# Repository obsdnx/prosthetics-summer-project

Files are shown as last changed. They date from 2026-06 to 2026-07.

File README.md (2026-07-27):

# Partial-Hand Prosthesis — Summer 2026

A co-design project to build a custom, body-powered prosthetic hand attachment for a specific client (Bassie), who has a limb difference affecting both hands. The device restores a functional grasp using 3D-printed parts and a cable-driven mechanism — no motors, no batteries.

---

## Goal

Design, prototype, and iterate on a body-powered prosthetic hand that:
- Restores functional grasp (closing fingers around an object and holding it) for a client with a partial-hand limb difference
- Is driven entirely by the user's own residual motion — thumb movement tensions a cable that closes the fingers; elastic bands return them
- Is 3D-printed so the team can go from a CAD change to a physical part in a few hours
- Is custom-fitted to the client's anatomy via a moulded thermoplastic baseplate
- Can be iterated rapidly in a university workshop setting

Two hands are being developed in parallel but with separate design tracks. The **right hand** (more tractable) is developed first; solutions are then adapted to the **left hand**, which has less residual motion and different anatomy.

---

## Mechanism

The adopted design combines two approaches:

| Approach | Source | Role |
|---|---|---|
| Cable + thumb-driven closing | Harshad | Active closing: thumb motion pulls a 0.55 mm cable routed through two capstans on the back of the hand, flexing all fingers simultaneously |
| Elastic band passive return | Fern (adapted from WILMER) | Passive opening: rubber bands return the fingers to their resting position when cable tension releases |

This gives a stronger and more controllable grasp than either approach alone. The mechanism is **underactuated** — one thumb input closes multiple joints across multiple fingers, and fingers naturally conform to the shape of whatever they grip.

---

## Components

| Component | Description |
|---|---|
| Thermoplastic baseplate | Rhinoplasty strips moulded directly to the back of the client's hand, then hardened — everything rivets or bonds to this |
| Capstans (×2) | Cable routing drums riveted to the baseplate; one thumb pull couples flexion across multiple fingers |
| Össur-style linkage digits | 5-part rigid linkage finger (Fern's design); 5 mm holes for metal dowel pin joints |
| Rolling contact joints (RCJ) | Alternative joint type — curved surfaces roll rather than pivot, no hardware needed; scaled to 50%, mirrored, with flanges |
| Knuckle hinge joints | 5 per hand × 2 hands; anchor the finger mechanisms to the baseplate at each knuckle |
| 0.55 mm cable | Runs from thumb through capstans to fingers |
| Elastic bands | Passive extension return |
| Magnetic wrist strap | Attachment to the hand — magnetic ends allow one-handed fastening |

**Left hand** uses a different strategy: one larger two-joint finger mechanism sized to the client's middle appendage, driven from the **wrist** rather than the thumb (wrist extension flexes the PIP joints; elastic band returns the distal joints).

---

## Project Summary

| Phase | Status |
|---|---|
| Research & concept selection | ✅ Complete (15 Jun) |
| Combined mechanism agreed | ✅ Complete (15 Jun) |
| Digit CAD (Össur-style linkage, right hand) | ✅ Complete (18 Jun) |
| Drive CAD (capstans, cable system) | ✅ Complete (18 Jun) |
| Rolling contact joint variants | ✅ Complete (18–19 Jun) |
| Attachment design (hinges, Velcro tabs, strap) | ✅ Complete (19 Jun) |
| Left-hand concept (wrist-driven) | ✅ Defined (19 Jun) |
| 3D printing & assembly | ✅ Began 22 Jun |
| First demo to Bassie | Target: 24 Jun |
| Iterative design cycle | Ongoing |

---

## Tech Stack

| Tool | Purpose |
|---|---|
| SolidWorks | Primary CAD tool for finger mechanism and wrist plate design (Varun) |
| CAD software (STEP output) | Parametric design — digits, hinges, capstans, chassis |
| Bambu Studio | Slicing STL files for the Bambu Lab X1 printer |
| Bambu Lab X1 | Primary FDM printer (PLA structural parts) |
| Ultimaker / Biolab printers | Secondary print facilities |
| Harshad's personal printer | Overnight backup printing |
| 3D scanner | Capturing client's hand geometry for custom fit |
| Thermoplastic moulding | Rhinoplasty strips shaped to the back of the hand for the baseplate |
| GitHub | Version control for CAD files, documentation, and research notes |

**Print settings:** 0.08 mm layer height, 15% infill, PLA. TPU considered for grip caps (deferred — conflicts with capacitive touch screen use).

---

## The Team

| Person | Area |
|---|---|
| Harshad | Cable-driven mechanism; owns 3D printing (personal printer backup); capstan and RCJ CAD models |
| Fern | Lead CAD for Össur-style linkage digit; WILMER elastic approach; left-hand wrist mechanism concept |
| Etienne | Rolling contact joint CAD adaptation |
| Eito | RCJ sizing for client's thumb; hollowed-out finger variant |
| Weasley | 3D modelling; design-for-manufacture; Hackspace liaison |
| Alex | Plan of Work and Hackspace access; safety/induction; fitted RCJ cap modelling |
| Anya | CAD support; 3D print/scan of left hand anatomy |
| Mervyn | Left-hand string-pulley concept; attachment methods; materials and biocompatibility research |
| Varun | Claw mechanism CAD (SolidWorks) — finger segments, wrist plate, spring hinges |
| Nikhil, Anais | Attended planning meeting (15 Jun) |

---

## Repository Structure

```
.
├── cad/
│   ├── step-files/            # STEP files for all designed components
│   ├── 3d-models/             # STL / print-ready files
│   └── varun-claw-mechanism/  # SolidWorks claw mechanism (see CAD Files below)
├── scans/                 # 3D scan data of client's hand
├── photos/
│   ├── arm/               # Fit photos on client's arm
│   └── misc/              # Build progress, prints, assembly
├── docs/                  # Meeting notes, design decisions, handover docs
└── research/              # Papers, competitor analysis, reference models
```

---

## CAD Files

### Varun — Claw Mechanism (SolidWorks)

The main finger mechanism, designed in SolidWorks. Two plate widths (original and narrow), three finger configurations, and two spring hinge variants. All files are `.SLDPRT` (parts) and `.SLDASM` (assemblies).

```
cad/varun-claw-mechanism/
├── V1-Equal-3-Segment-Hand/     # 3 equal-length segments, original plate width
├── V1-Wrist-Plate/              # Upper + lower wrist plate
├── V1-Brackets/                 # Path bracket + hook mount
├── V2-Equal-3-Segment-Hand/     # Narrow plate, equal segments
├── V2-Non-Equal-3-Segment-Hand/ # Narrow plate, varying segment lengths
├── V2-2-Segment-Hand/           # Narrow plate, 2-segment variant
├── V2-Wrist-Plate/              # Narrow wrist plate
├── V2-Brackets/                 # Path bracket + hook mount
├── V2-Spring-Hinge/             # Spring hinge assembly (th-61-1)
└── V2-Spring-Hinge-2/           # Spring hinge variant (th-61sus-1)
```

### Legacy STEP files

| Component | Version | File |
|---|---|---|
| Outer phalange | V3 | `cad/step-files/V3 Outer phalange.STEP` |
| Hinge | V2 | `cad/step-files/V2 Hinge.STEP` |

---

## Progress Photos

### Claw mechanism — July 2026

**All CAD parts laid out (V2 narrow plate)**
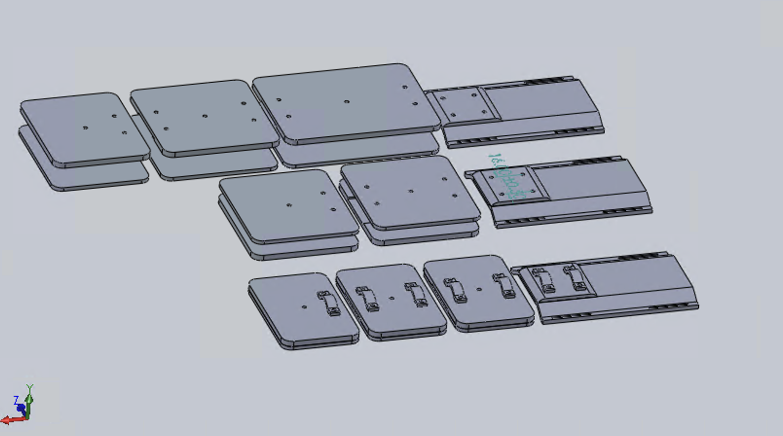
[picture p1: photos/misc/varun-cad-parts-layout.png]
Varun CAD parts layout


**Wrist plate fitted on arm with Velcro straps and spring hinge**
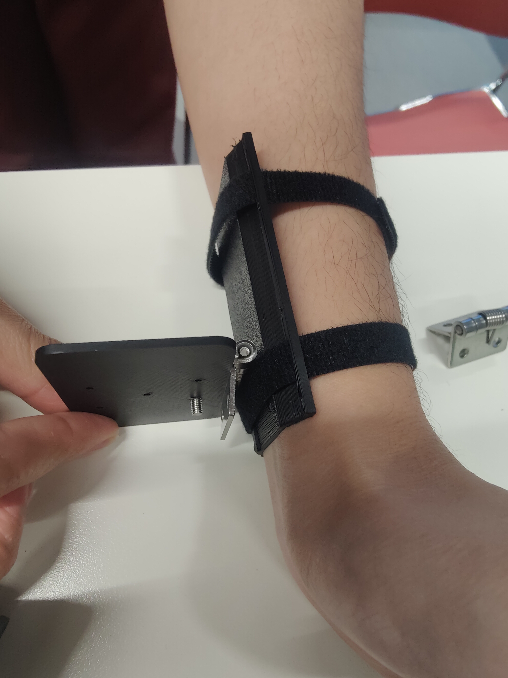
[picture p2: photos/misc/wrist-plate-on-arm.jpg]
Wrist plate on arm


**Wrist plate hinge flexing — showing range of motion**
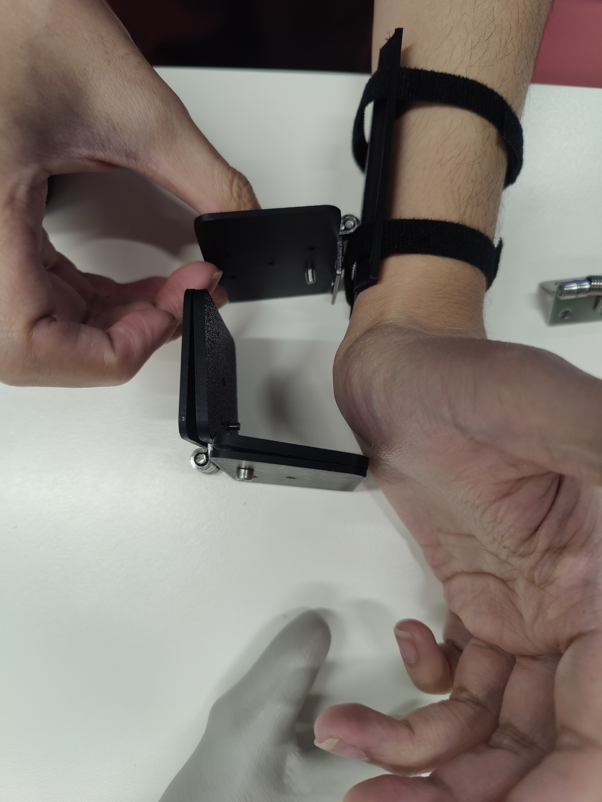
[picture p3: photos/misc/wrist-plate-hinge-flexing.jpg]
Wrist plate hinge flexing


**Full assembly — left hand (black) and right hand (yellow) with cable routing**
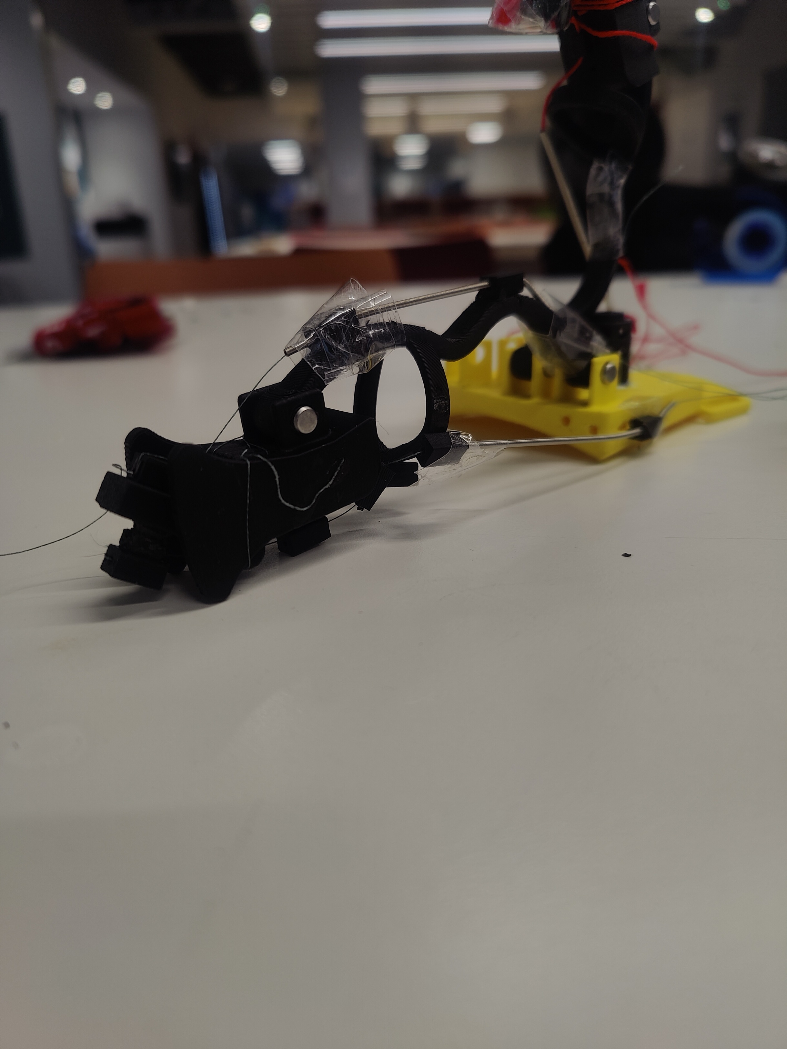
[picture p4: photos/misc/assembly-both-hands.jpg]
Both hands assembled


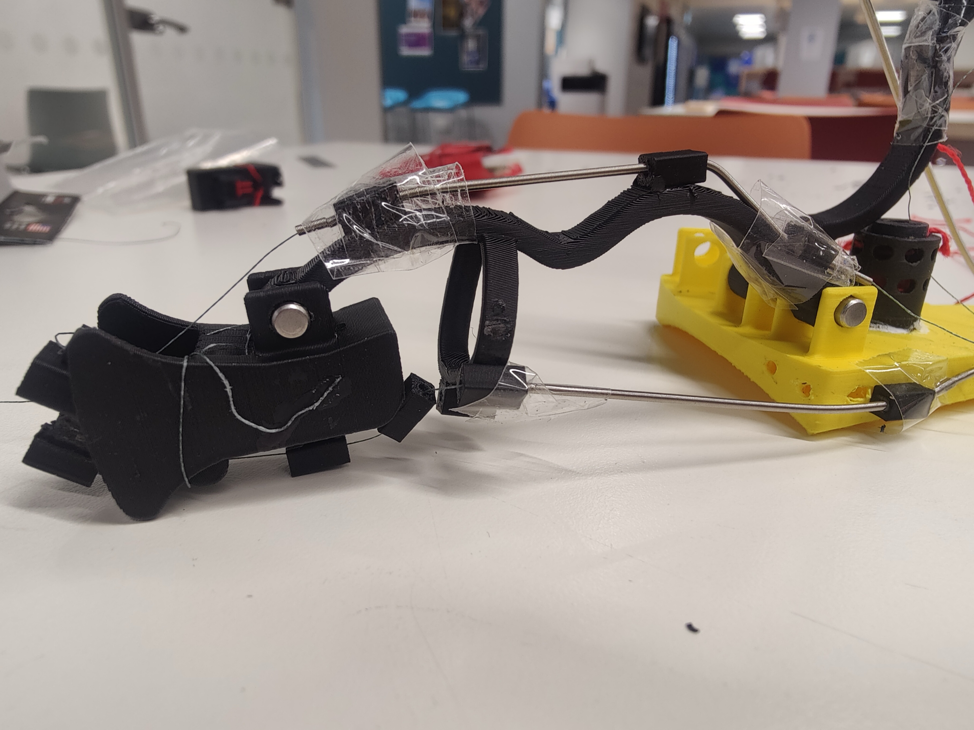
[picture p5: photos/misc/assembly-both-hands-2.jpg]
Both hands assembled, second angle


**Left hand mechanism — close-up of cable and finger segments**
Left hand cable detail

### Early chassis work

**Chassis CAD model**
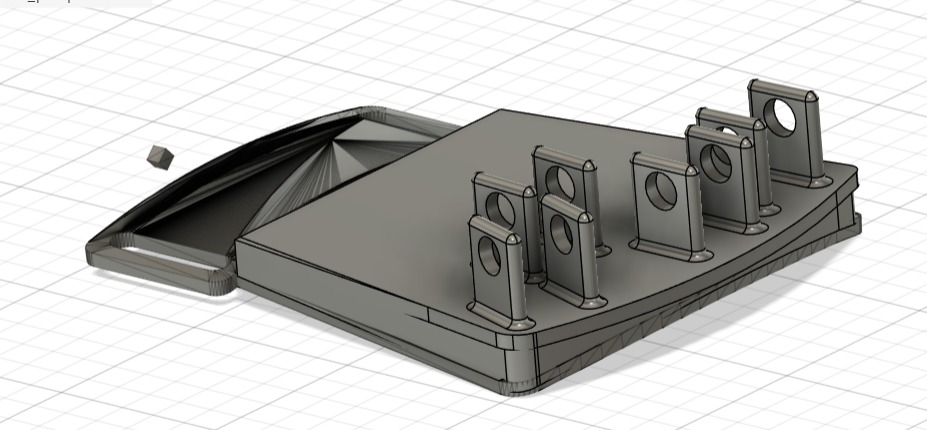
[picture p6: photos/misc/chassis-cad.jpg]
Chassis CAD model


**Chassis design fitted on hand model**
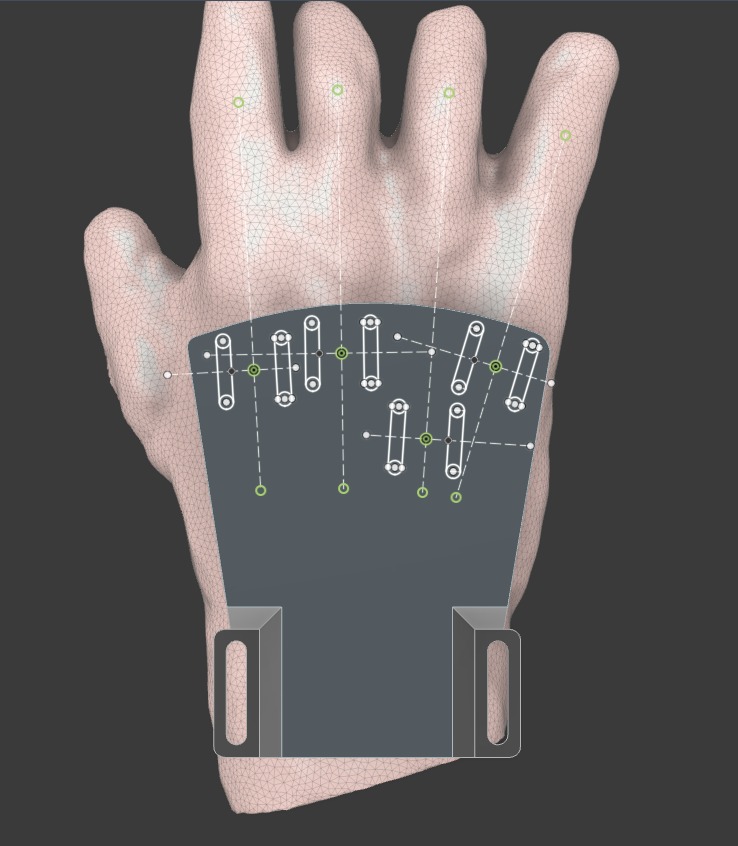
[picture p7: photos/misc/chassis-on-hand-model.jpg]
Chassis on hand model


**Physical 3D print — blue chassis**
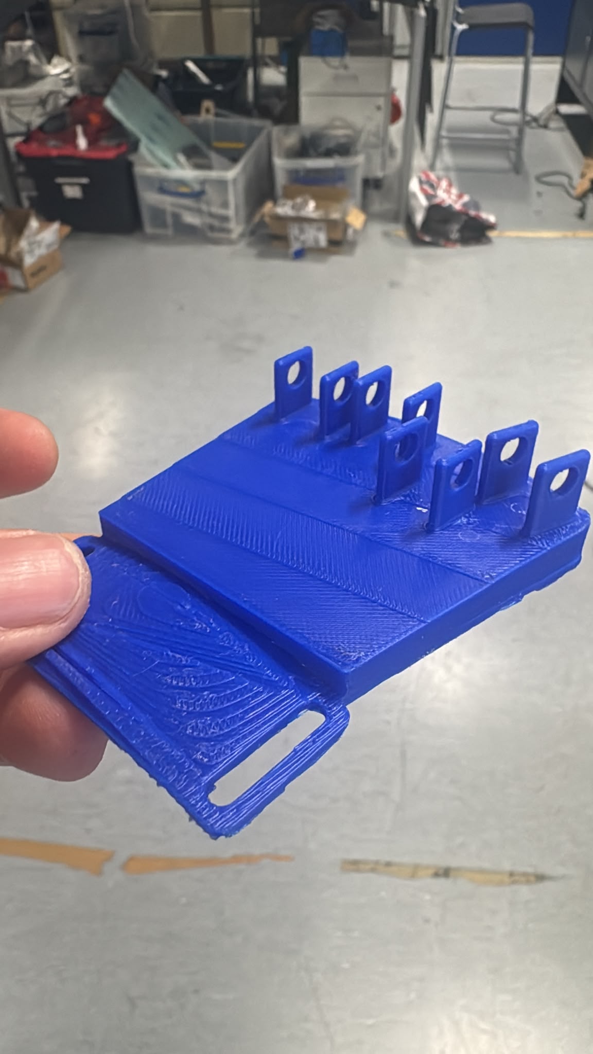
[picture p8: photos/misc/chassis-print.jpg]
3D printed chassis


**Bambu Studio — underplate slicer setup**
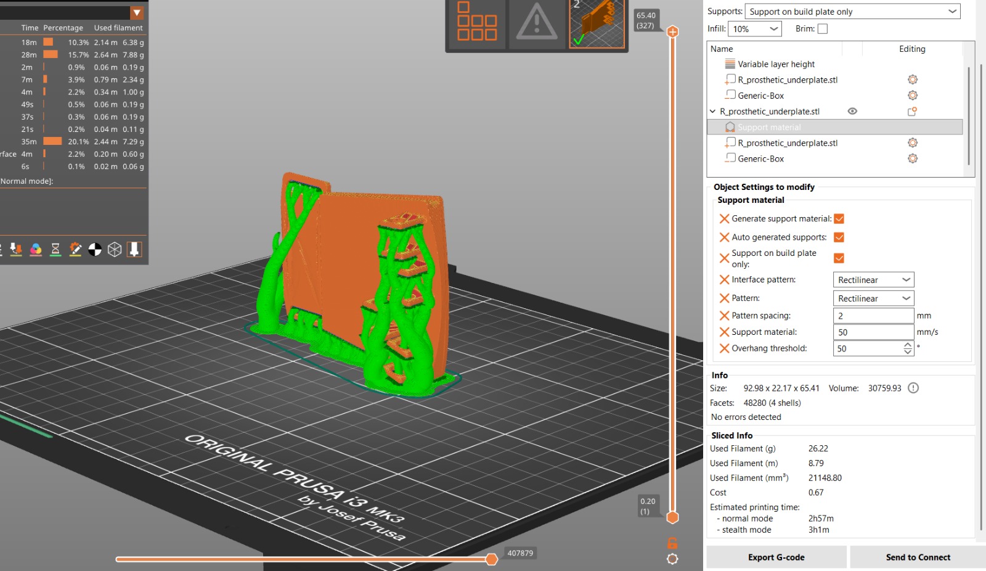
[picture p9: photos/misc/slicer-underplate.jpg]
Slicer underplate


---

## References

- [A Body-Powered Underactuated Prosthetic Finger Driven by MCP Joint Motion (2025)](https://doi.org/10.3390/robotics14080107) — basis for Harshad's cable-driven mechanism (see Figure 2)
- [The WILMER Passive Hand Prosthesis for Toddlers (2009)](https://doi.org/10.1097/JPO.0b013e31819ed6a7) — basis for Fern's elastic-band return approach
- [Knick prosthetic finger v3.55 — Printables](https://www.printables.com/model/653551-knick-prosthetic-finger-v-355) — reference model for the left-hand single-finger mechanism
- [MagSnap magnetic strap system](https://wrapitstorage.com/pages/magsnap) — reference for magnetic wrist attachment
- Össur MCPinky-style partial-hand linkage — *reference needed*
- PIPDriver mechanism — *reference needed*

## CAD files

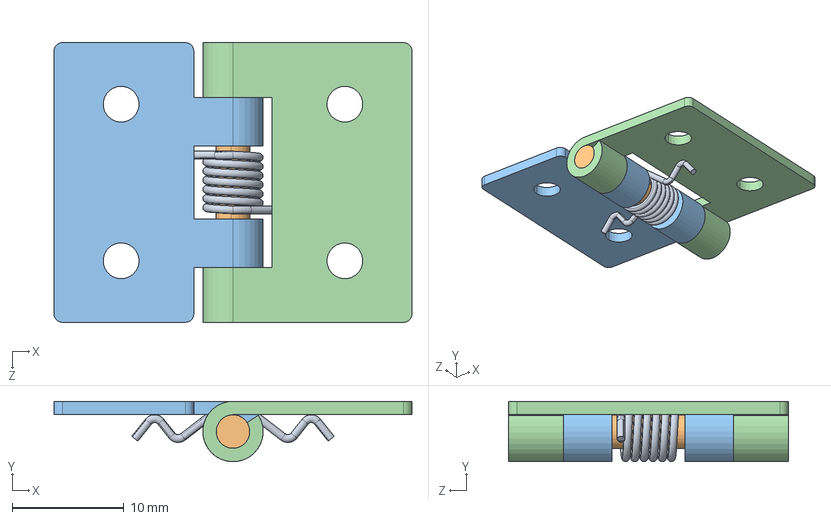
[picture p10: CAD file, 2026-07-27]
cad/varun-claw-mechanism/V2-Spring-Hinge-2/th-61sus-1.SLDASM
32.0 x 5.40 x 25.0 mm
th-61sus-1_01
th-61sus-1_02
th-61sus-1_03
th-61sus-1_04

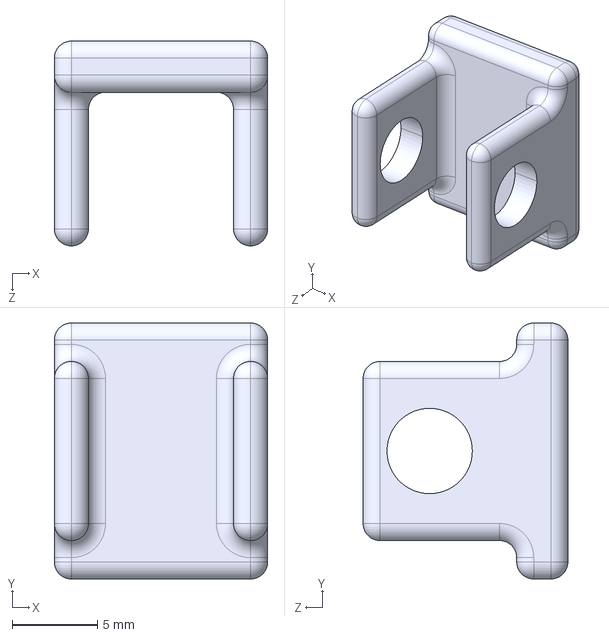
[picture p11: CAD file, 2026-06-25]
cad/step-files/V2 Hinge.STEP
12.5 x 15.0 x 12.0 mm

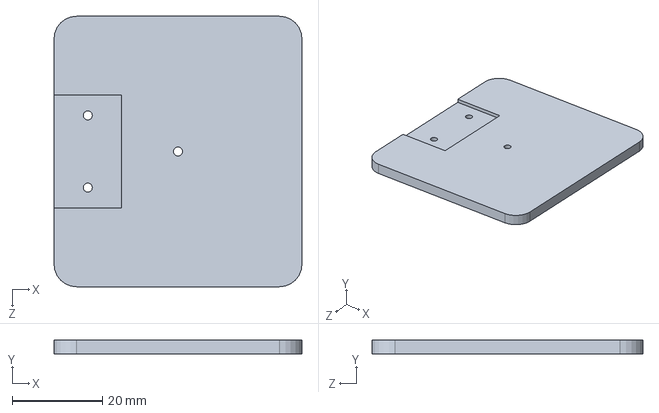
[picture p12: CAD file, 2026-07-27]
cad/varun-claw-mechanism/V2-2-Segment-Hand/03-01 End Segment Hinge Side.SLDPRT
55.0 x 3.00 x 60.0 mm

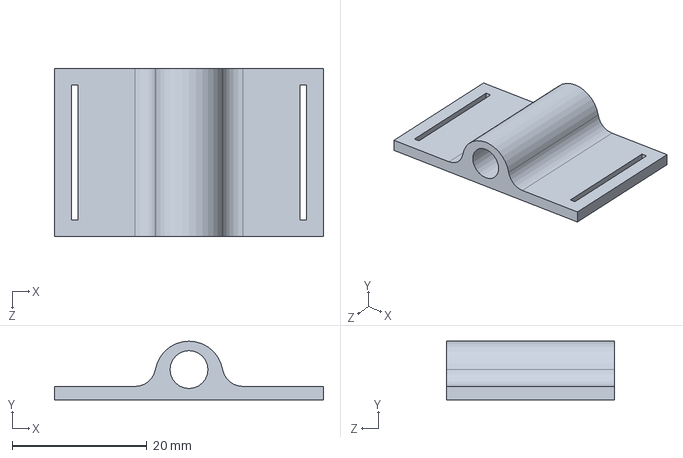
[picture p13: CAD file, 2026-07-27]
cad/varun-claw-mechanism/V2-Brackets/05-02 Hook Mount.SLDPRT
40.0 x 8.72 x 25.0 mm

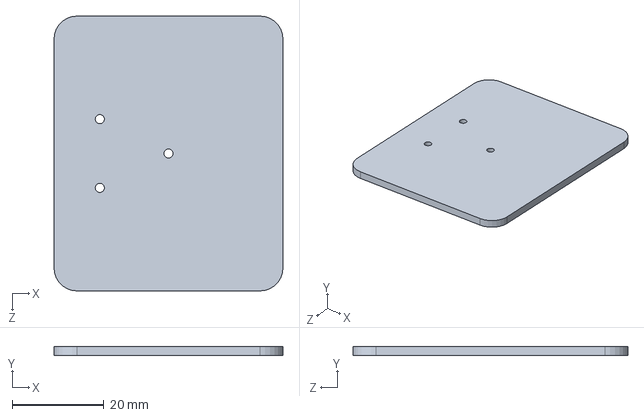
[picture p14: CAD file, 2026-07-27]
cad/varun-claw-mechanism/V2-Equal-3-Segment-Hand/01-01 End Plate Flat Side.SLDPRT
50.0 x 2.00 x 60.0 mm

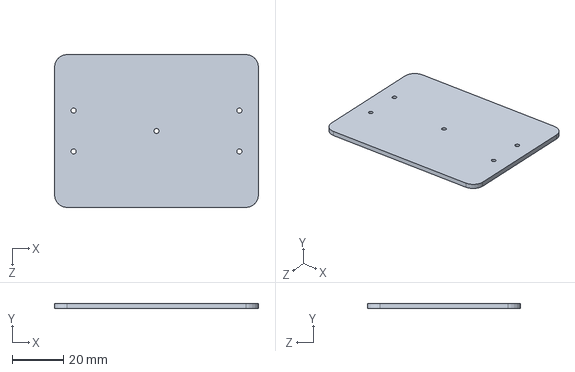
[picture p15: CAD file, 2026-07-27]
cad/varun-claw-mechanism/V2-Non-Equal-3-Segment-Hand/02-01 Start Segment Flat Side.SLDPRT
80.0 x 2.00 x 60.0 mm

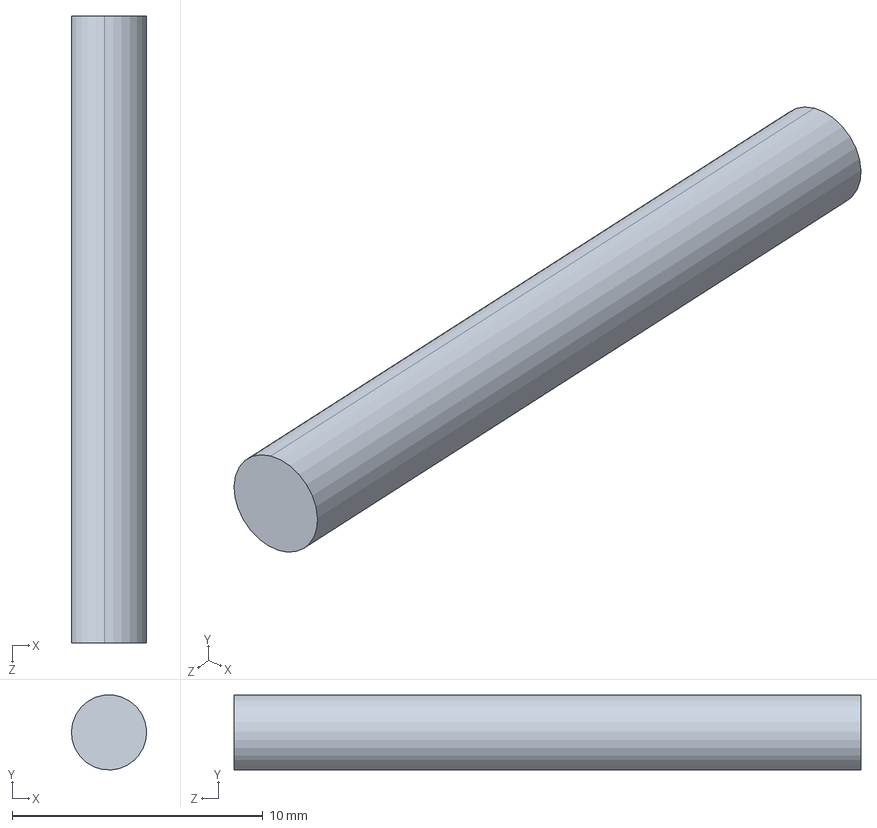
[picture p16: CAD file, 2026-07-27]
cad/varun-claw-mechanism/V2-Spring-Hinge-2/th-61sus-1_02.SLDPRT
3.00 x 2.99 x 25.0 mm

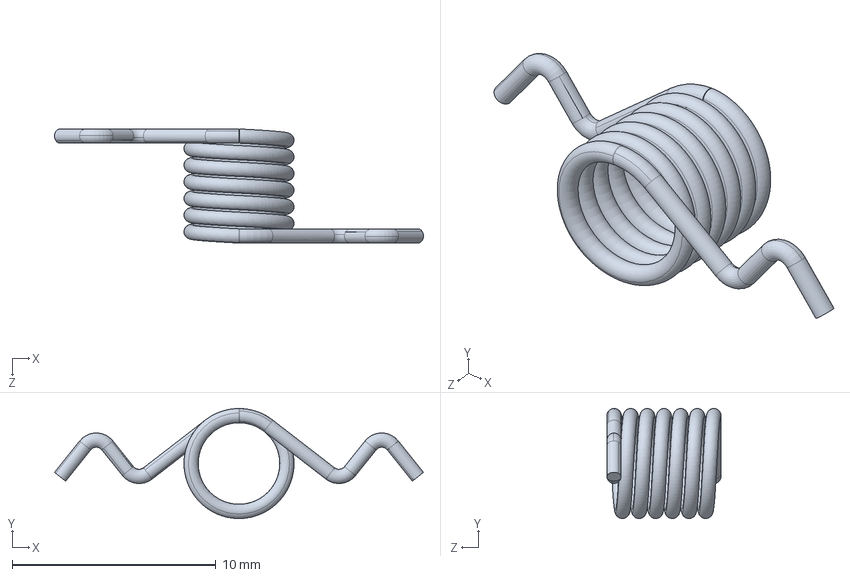
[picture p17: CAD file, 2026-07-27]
cad/varun-claw-mechanism/V2-Spring-Hinge/th-61-1_01.SLDPRT
18.1 x 5.40 x 5.60 mm

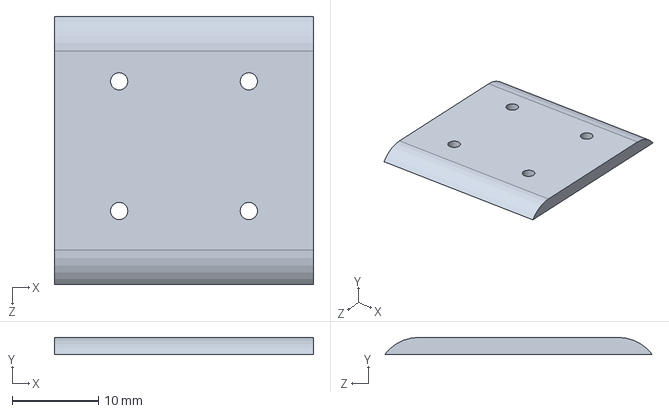
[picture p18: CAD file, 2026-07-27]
cad/varun-claw-mechanism/V2-Wrist-Plate/04-02 Upper Wrist Plate.SLDPRT
30.0 x 2.00 x 31.0 mm

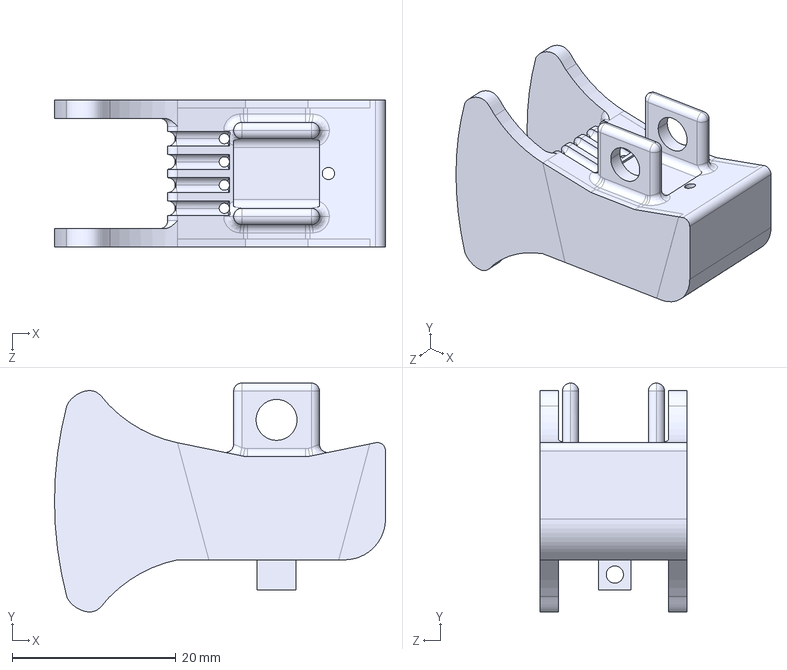
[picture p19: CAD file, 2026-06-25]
cad/step-files/V3 Outer phalange.STEP
40.5 x 28.0 x 18.0 mm

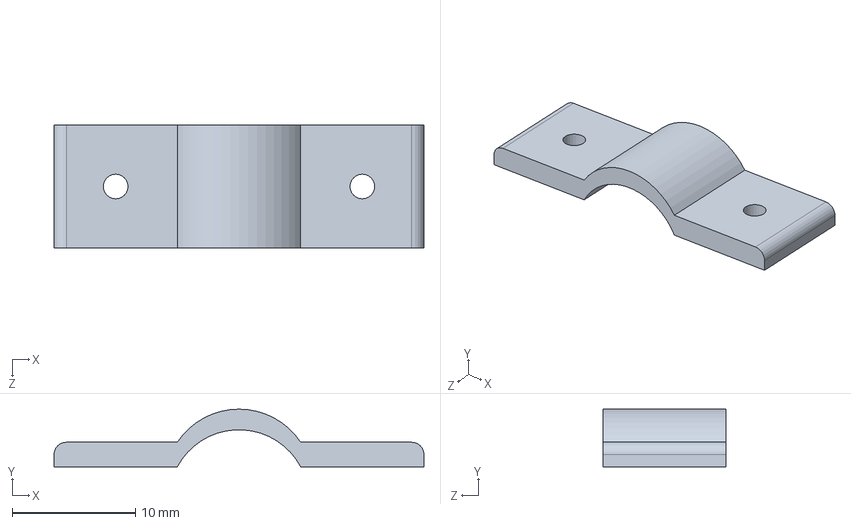
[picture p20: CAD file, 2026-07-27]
cad/varun-claw-mechanism/V2-Brackets/05-01 Path Bracket.SLDPRT
30.0 x 4.68 x 10.0 mm

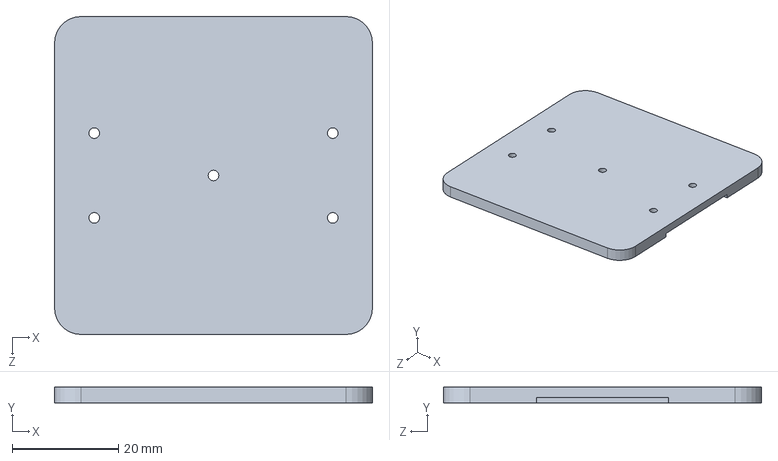
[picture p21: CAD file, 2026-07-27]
cad/varun-claw-mechanism/V2-Non-Equal-3-Segment-Hand/02-03 Middle Segment Hinge Side.SLDPRT
60.0 x 3.00 x 60.0 mm

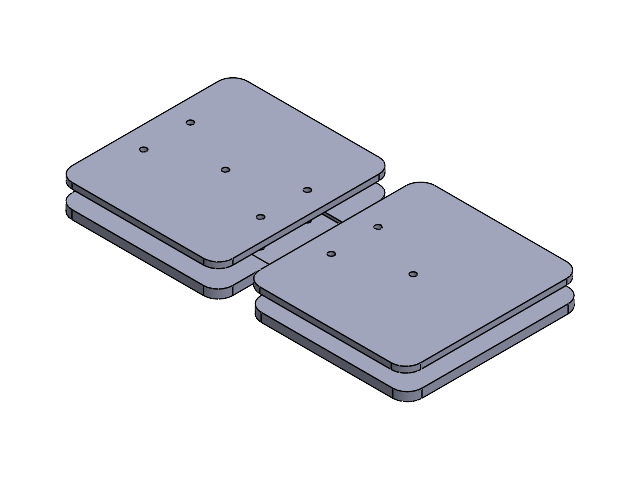
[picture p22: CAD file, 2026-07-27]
cad/varun-claw-mechanism/V2-2-Segment-Hand/03 Full Assembly.SLDASM
03-01 End Segment Hinge Side
03-02 End Segment Flat Side
03-03 Start Segment Hinge Side
03-04 Start Segment Flat Side

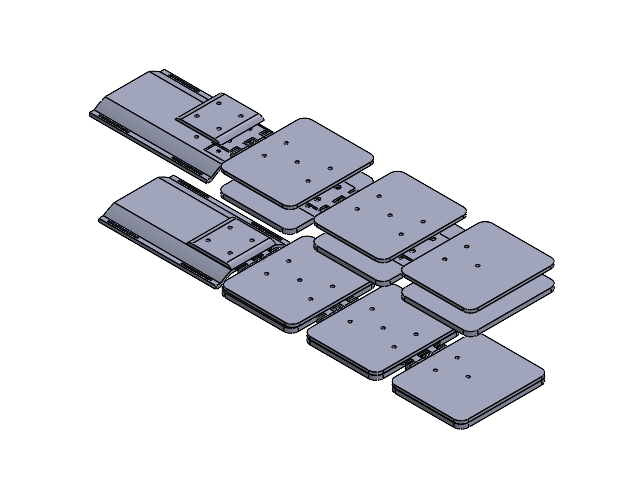
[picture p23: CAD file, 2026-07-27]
cad/varun-claw-mechanism/V2-Equal-3-Segment-Hand/01 Full Assembly.SLDASM
01-01 End Plate Flat Side x 2
01-02 End Plate Hinge Side x 2
01-03 Middle Plate Flat Side x 2
01-04 Middle Plate Hinge Side x 2
01-05 Start Plate Flat Side x 2
01-06 Start Plate Hinge Side x 2
04-01 Lower Wrist Plate x 2
04-02 Upper Wrist Plate x 2
th-61sus-1_01 x 6
th-61sus-1_02 x 6
th-61sus-1_03 x 6
th-61sus-1_04 x 6

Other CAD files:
cad/varun-claw-mechanism/V2-Spring-Hinge/th-61-1.SLDASM
cad/varun-claw-mechanism/V2-Non-Equal-3-Segment-Hand/02 Full Assembly.SLDASM
cad/varun-claw-mechanism/V2-Spring-Hinge-2/th-61sus-1_01.SLDPRT
cad/varun-claw-mechanism/V2-Spring-Hinge/th-61-1_02.SLDPRT
cad/varun-claw-mechanism/V1-Brackets/05-01 Path Bracket.SLDPRT
cad/varun-claw-mechanism/V1-Brackets/05-02 Hook Mount.SLDPRT
cad/varun-claw-mechanism/V1-Equal-3-Segment-Hand/01 - 01 End Segment Hinge Side Bumper.SLDPRT
cad/varun-claw-mechanism/V1-Equal-3-Segment-Hand/01 Full Assembly-prd-avd-25-055.SLDASM
cad/varun-claw-mechanism/V1-Equal-3-Segment-Hand/01 Full Assembly.SLDASM
cad/varun-claw-mechanism/V1-Equal-3-Segment-Hand/01-01 End Segment Flat Side Bumper.x_t.SLDPRT
cad/varun-claw-mechanism/V1-Equal-3-Segment-Hand/01-01 End Segment Hinge Side.SLDPRT
cad/varun-claw-mechanism/V1-Equal-3-Segment-Hand/01-02 End Segment Flat Side.SLDPRT
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

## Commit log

2026-06-25 Set up repo structure and comprehensive README for prosthetics project (#1)
    - Full README with goal, final product summary, component table, tech stack, and repo structure
    - Added V3 Outer phalange and V2 Hinge STEP files to cad/step-files/
    - Created folder structure: cad, scans, photos, docs, research
    [V2 Hinge.STEP, V3 Outer phalange.STEP]
2026-07-27 Add progress photos and Bambu Studio to tech stack (#2)
    [01 - 01 End Segment Hinge Side Bumper.SLDPRT, 01 Full Assembly-prd-avd-25-055.SLDASM, 01 Full Assembly.SLDASM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]
2026-07-27 Fix broken reference DOIs and add claw mechanism dir to structure tree
    The cable-driven finger paper DOI was a 404 (published in MDPI
    Robotics, not IEEE RA-L) and the WILMER DOI resolved to an unrelated
    paper. Both replaced with Crossref-verified DOIs. Also list
    cad/varun-claw-mechanism/ in the repository structure tree.
